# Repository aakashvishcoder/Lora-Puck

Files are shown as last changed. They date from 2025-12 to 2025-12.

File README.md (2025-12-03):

# Lora Puck

This is my version of a Lora Puck, which is a compact, low-power wireless communication module that can send and receive data from several kilometers away! This puck has several unique features and parts (as listed below), and includes a temperature sensor as well! This is one of my first ever PCBs, so it most definitely has some flaws!

# Features:
- USBC Receptacle
- Programmable Microcontroller

# Images:






# Build of Materials (BOM)

| Item | Description | Qty | Product link | Price w/ Tax ($) | Running Total |
|---|---|-----|---|---|---|
| Capacitor | 100nF (0.1uF) | 13 | [link](https://jlcpcb.com/partdetail/1877-CL05B104KO5NNNC/C1525) | $0.21 | $0.21 |
| Capacitor | 1uF | 2 | [link](https://jlcpcb.com/partdetail/53938-CL05A105KA5NQNC/C52923) | $0.06 | $0.27 |
| Capacitor | 47nF | 1 | [link](https://jlcpcb.com/partdetail/YAGEO-CC0402KRX7R9BB473/C1532) | $0.02 | $0.29 |
| Capacitor | 47pF | 1 | [link](https://jlcpcb.com/partdetail/YAGEO-CC0402JRNPO9BN470/C1549) | $0.01 | $0.30 |
| Capacitor | 1nF | 1 | [link](https://jlcpcb.com/partdetail/YAGEO-CC0402KRX7R9BB102/C1522) | $0.01 | $0.31 |
| Capacitor | 39pF | 1 | [link](https://jlcpcb.com/partdetail/YAGEO-CC0402JRNPO9BN390/C1548) | $0.01 | $0.32 |
| Capacitor | 3.3pF | 4 | [link](https://jlcpcb.com/partdetail/YAGEO-CC0402JRNPO9BN3R3/C1546) | $0.04 | $0.36 |
| Capacitor | 10uF | 2 | [link](https://jlcpcb.com/partdetail/SamsungElectro-CL05A106MQ5NUNC/C15525) | $0.06 | $0.42 |
| Capacitor | 470nF | 1 | [link](https://jlcpcb.com/partdetail/YAGEO-CC0402KRX7R9BB471/C1779) | $0.02 | $0.44 |
| Inductor | 15uH | 1 | [link](https://jlcpcb.com/partdetail/Sunlord-SDCL1005C150KTDF/C285676) | $0.05 | $0.49 |
| Inductor | 47nH | 1 | [link](https://jlcpcb.com/partdetail/JohansonTech-L-0402_47nH/C284438) | $0.05 | $0.54 |
| Inductor | 9.1nH | 1 | [link](https://jlcpcb.com/partdetail/JohansonTech-L-0402_9_1nH/C284437) | $0.05 | $0.59 |
| Ferrite Bead | Ferrite 0402 | 1 | [link](https://jlcpcb.com/partdetail/Sunlord-SDCL1005C4N7STDF/C8589) | $0.01 | $0.60 |
| Balun | Johanson 0900FM15K0039 | 1 | [link](https://jlcpcb.com/partdetail/JohansonTech-0900FM15K0039/C284439) | $0.85 | $1.45 |
| Resistor | 10k | 1 | [link](https://jlcpcb.com/partdetail/UNIROYAL-0402WGF1002TCE/C25804) | $0.01 | $1.46 |
| Resistor | 4.7k | 2 | [link](https://jlcpcb.com/partdetail/UNIROYAL-0402WGF4701TCE/C25867) | $0.02 | $1.48 |
| Resistor | 27.4Ω | 2 | [link](https://jlcpcb.com/partdetail/UNIROYAL-0402WGF270JTCE/C23154) | $0.02 | $1.50 |
| Resistor | 1k | 2 | [link](https://jlcpcb.com/partdetail/UNIROYAL-0402WGF1001TCE/C11702) | $0.02 | $1.52 |
| Resistor | 100Ω | 1 | [link](https://jlcpcb.com/partdetail/UNIROYAL-0402WGF1000TCE/C25086) | $0.01 | $1.53 |
| Resistor | 5.1k | 2 | [link](https://jlcpcb.com/partdetail/UNIROYAL-0402WGF5101TCE/C25905) | $0.02 | $1.55 |
| Switch | Tactile Button | 2 | [link](https://jlcpcb.com/partdetail/XKBConnectivity-TS1187ABAB/C318884) | $0.84 | $2.39 |
| USB Receptacle | USB-C 16P | 1 | [link](https://jlcpcb.com/partdetail/Korean_HropartsElec-TYPEC31M12/C165948) | $0.85 | $3.24 |
| IC | LoRa SX1262 | 1 | [link](https://jlcpcb.com/partdetail/Semtech-SX1262IMLTRT/C967207) | $6.50 | $9.74 |
| IC | RP2040 MCU | 1 | [link](https://jlcpcb.com/partdetail/RaspberryPi-RP2040/C2040) | $4.58 | $14.32 |
| IC | Flash W25Q128JVS | 1 | [link](https://jlcpcb.com/partdetail/Winbond-W25Q128JVSIQ/C97521) | $2.67 | $16.99 |
| IC | RF Switch PE4259 | 1 | [link](https://jlcpcb.com/partdetail/PeregrineSemiconductor-PE4259/C285440) | $1.20 | $18.19 |
| IC | Regulator AP2112K-3.3 | 1 | [link](https://jlcpcb.com/partdetail/DiodesInc-AP2112K3_3TRG1/C15630) | $0.12 | $18.31 |
| Sensor | SHTC3 Humidity/Temp | 1 | [link](https://jlcpcb.com/partdetail/Sensirion-SHTC3/C2844388) | $2.80 | $21.11 |
| Crystal | 32MHz 3225 | 1 | [link](https://jlcpcb.com/partdetail/YXC-X322532MSB4SI/C9003) | $0.32 | $21.43 |
| Crystal | 12MHz 3225 | 1 | [link](https://jlcpcb.com/partdetail/YXC-X322512MSB4SI/C9002) | $0.32 | $21.75 |
| LoRa-Puck PCB | PCBA board assembly | 1 | [link](https://cart.jlcpcb.com/) | $43.94 | $65.69 |

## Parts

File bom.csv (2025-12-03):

Item | Description | Quantity | Product link | Price w/ Tax ($) | Running Total
Capacitor | 100nF (0.1uF) | 13 | https://jlcpcb.com/partdetail/1877-CL05B104KO5NNNC/C1525 | $0.21 | $0.21
Capacitor | 1uF | 2 | https://jlcpcb.com/partdetail/53938-CL05A105KA5NQNC/C52923 | $0.06 | $0.27
Capacitor | 47nF | 1 | https://jlcpcb.com/partdetail/YAGEO-CC0402KRX7R9BB473/C1532 | $0.02 | $0.29
Capacitor | 47pF | 1 | https://jlcpcb.com/partdetail/YAGEO-CC0402JRNPO9BN470/C1549 | $0.01 | $0.30
Capacitor | 1nF | 1 | https://jlcpcb.com/partdetail/YAGEO-CC0402KRX7R9BB102/C1522 | $0.01 | $0.31
Capacitor | 39pF | 1 | https://jlcpcb.com/partdetail/YAGEO-CC0402JRNPO9BN390/C1548 | $0.01 | $0.32
Capacitor | 3.3pF | 4 | https://jlcpcb.com/partdetail/YAGEO-CC0402JRNPO9BN3R3/C1546 | $0.04 | $0.36
Capacitor | 10uF | 2 | https://jlcpcb.com/partdetail/SamsungElectro-CL05A106MQ5NUNC/C15525 | $0.06 | $0.42
Capacitor | 470nF | 1 | https://jlcpcb.com/partdetail/YAGEO-CC0402KRX7R9BB471/C1779 | $0.02 | $0.44
Inductor | 15uH | 1 | https://jlcpcb.com/partdetail/Sunlord-SDCL1005C150KTDF/C285676 | $0.05 | $0.49
Inductor | 47nH | 1 | https://jlcpcb.com/partdetail/JohansonTech-L-0402_47nH/C284438 | $0.05 | $0.54
Inductor | 9.1nH | 1 | https://jlcpcb.com/partdetail/JohansonTech-L-0402_9_1nH/C284437 | $0.05 | $0.59
Ferrite Bead | Ferrite 0402 | 1 | https://jlcpcb.com/partdetail/Sunlord-SDCL1005C4N7STDF/C8589 | $0.01 | $0.60
Balun | Johanson 0900FM15K0039 | 1 | https://jlcpcb.com/partdetail/JohansonTech-0900FM15K0039/C284439 | $0.85 | $1.45
Resistor | 10k | 1 | https://jlcpcb.com/partdetail/UNIROYAL-0402WGF1002TCE/C25804 | $0.01 | $1.46
Resistor | 4.7k | 2 | https://jlcpcb.com/partdetail/UNIROYAL-0402WGF4701TCE/C25867 | $0.02 | $1.48
Resistor | 27.4Ω | 2 | https://jlcpcb.com/partdetail/UNIROYAL-0402WGF270JTCE/C23154 | $0.02 | $1.50
Resistor | 1k | 2 | https://jlcpcb.com/partdetail/UNIROYAL-0402WGF1001TCE/C11702 | $0.02 | $1.52
Resistor | 100Ω | 1 | https://jlcpcb.com/partdetail/UNIROYAL-0402WGF1000TCE/C25086 | $0.01 | $1.53
Resistor | 5.1k | 2 | https://jlcpcb.com/partdetail/UNIROYAL-0402WGF5101TCE/C25905 | $0.02 | $1.55
Switch | Tactile Button | 2 | https://jlcpcb.com/partdetail/XKBConnectivity-TS1187ABAB/C318884 | $0.84 | $2.39
USB Receptacle | USB-C 16P | 1 | https://jlcpcb.com/partdetail/Korean_HropartsElec-TYPEC31M12/C165948 | $0.85 | $3.24
IC | LoRa SX1262 | 1 | https://jlcpcb.com/partdetail/Semtech-SX1262IMLTRT/C967207 | $6.50 | $9.74
IC | RP2040 MCU | 1 | https://jlcpcb.com/partdetail/RaspberryPi-RP2040/C2040 | $4.58 | $14.32
IC | Flash W25Q128JVS | 1 | https://jlcpcb.com/partdetail/Winbond-W25Q128JVSIQ/C97521 | $2.67 | $16.99
IC | RF Switch PE4259 | 1 | https://jlcpcb.com/partdetail/PeregrineSemiconductor-PE4259/C285440 | $1.20 | $18.19
IC | Regulator AP2112K-3.3 | 1 | https://jlcpcb.com/partdetail/DiodesInc-AP2112K3_3TRG1/C15630 | $0.12 | $18.31
Sensor | SHTC3 Humidity/Temp | 1 | https://jlcpcb.com/partdetail/Sensirion-SHTC3/C2844388 | $2.80 | $21.11
Crystal | 32MHz 3225 | 1 | https://jlcpcb.com/partdetail/YXC-X322532MSB4SI/C9003 | $0.32 | $21.43
Crystal | 12MHz 3225 | 1 | https://jlcpcb.com/partdetail/YXC-X322512MSB4SI/C9002 | $0.32 | $21.75
LoRa-Puck PCB | PCBA board assembly | 1 | N/A (https://cart.jlcpcb.com/) | $43.94 | $65.69

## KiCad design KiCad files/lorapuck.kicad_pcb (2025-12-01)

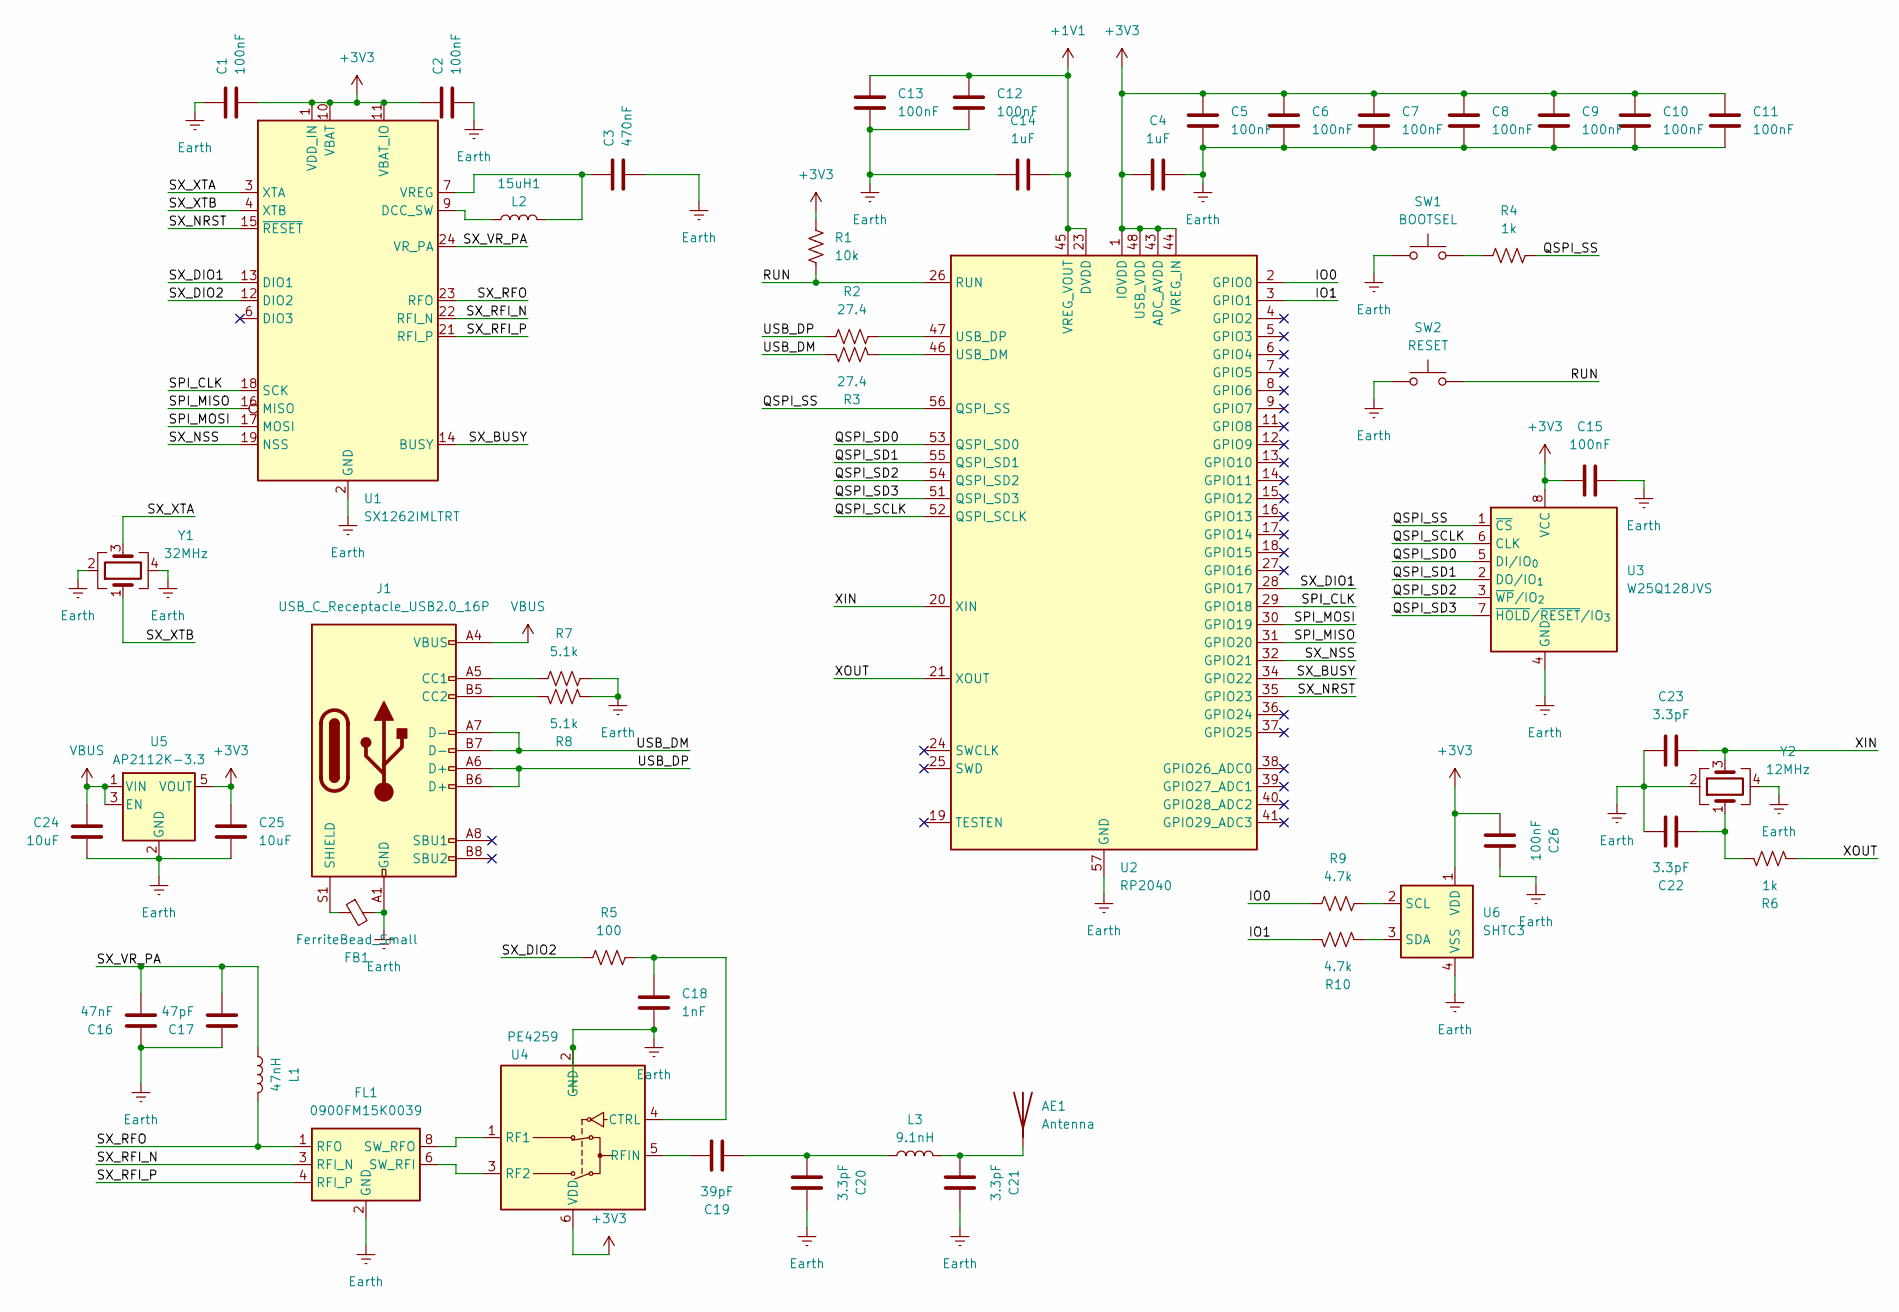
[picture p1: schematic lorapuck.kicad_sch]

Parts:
15uH1: L2; L_0402_1005Metric
AE1: Antenna; PinSocket_1x01_P2.54mm_Vertical
C1, C2, C5, C6, C7, C8, C9, C10, C11, C12, C13, C15, C26: 100nF; C_0402_1005Metric
C3: 470nF; C_0402_1005Metric
C4, C14: 1uF; C_0402_1005Metric
C16: 47nF; C_0402_1005Metric
C17: 47pF; C_0402_1005Metric
C18: 1nF; C_0402_1005Metric
C19: 39pF; C_0402_1005Metric
C20, C21, C22, C23: 3.3pF; C_0402_1005Metric
C24, C25: 10uF; C_0402_1005Metric
FB1: FerriteBead_Small; L_0402_1005Metric
FL1: 0900FM15K0039; Balun_Johanson_0900FM15K0039
J1: USB_C_Receptacle_USB2.0_16P; USB_C_Receptacle_GCT_USB4105-xx-A_16P_TopMnt_Horizontal
L1: 47nH; L_0402_1005Metric
L3: 9.1nH; L_0402_1005Metric
R1: 10k; R_0402_1005Metric
R2, R3: 27.4; R_0402_1005Metric
R4, R6: 1k; R_0402_1005Metric
R5: 100; R_0402_1005Metric
R7, R8: 5.1k; R_0402_1005Metric
R9, R10: 4.7k; R_0402_1005Metric
SW1: BOOTSEL; SW_Tactile_SPST_NO_Straight_CK_PTS636Sx25SMTRLFS
SW2: RESET; SW_Tactile_SPST_NO_Straight_CK_PTS636Sx25SMTRLFS
U1: SX1262IMLTRT; QFN-24-1EP_4x4mm_P0.5mm_EP2.6x2.6mm
U2: RP2040; QFN-56-1EP_7x7mm_P0.4mm_EP3.2x3.2mm
U3: W25Q128JVS; SOIC-8_5.3x5.3mm_P1.27mm
U4: PE4259; SOT-363_SC-70-6
U5: AP2112K-3.3; SOT-23-5
U6: SHTC3; Sensirion_DFN-4-1EP_2x2mm_P1mm_EP0.7x1.6mm
Y1: 32MHz; Crystal_SMD_3225-4Pin_3.2x2.5mm
Y2: 12MHz; Crystal_SMD_Abracon_ABM8G-4Pin_3.2x2.5mm

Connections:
+1V1: C12.2, C13.2, C14.2, U2.23 (DVDD), U2.45 (VREG_VOUT), U2.50 (DVDD)
+3V3: C1.2, C2.1, C4.1, C5.2, C6.2, C7.2, C8.2, C9.2, C10.2, C11.2, C15.2, C25.1, C26.2, R1.1, U1.1 (VDD_IN), U1.10 (VBAT), U1.11 (VBAT_IO), U2.1 (IOVDD), U2.10 (IOVDD), U2.22 (IOVDD), U2.33 (IOVDD), U2.42 (IOVDD), U2.43 (ADC_AVDD), U2.44 (VREG_IN), U2.48 (USB_VDD), U2.49 (IOVDD), U3.8 (VCC), U4.6 (VDD), U5.5 (VOUT), U6.1 (VDD)
/<NO NET>: U1.15 (~RESET), U2.35 (GPIO23)
/IO0: R9.1, U2.2 (GPIO0)
/IO1: R10.2, U2.3 (GPIO1)
/QSPI_SCLK: U2.52 (QSPI_SCLK), U3.6 (CLK)
/QSPI_SD0: U2.53 (QSPI_SD0), U3.5 (DI/IO_{0})
/QSPI_SD1: U2.55 (QSPI_SD1), U3.2 (DO/IO_{1})
/QSPI_SD2: U2.54 (QSPI_SD2), U3.3 (~WP/IO_{2})
/QSPI_SD3: U2.51 (QSPI_SD3), U3.7 (~HOLD/~RESET/IO_{3})
/QSPI_SS: R4.1, U2.56 (QSPI_SS), U3.1 (~CS)
/RUN: R1.2, SW2.2, U2.26 (RUN)
/SPI_CLK: U1.18 (SCK), U2.29 (GPIO18)
/SPI_MISO: U1.16 (MISO), U2.31 (GPIO20)
/SPI_MOSI: U1.17 (MOSI), U2.30 (GPIO19)
/SX_BUSY: U1.14 (BUSY), U2.34 (GPIO22)
/SX_DIO1: U1.13 (DIO1), U2.28 (GPIO17)
/SX_DIO2: R5.1, U1.12 (DIO2)
/SX_NSS: U1.19 (NSS), U2.32 (GPIO21)
/SX_RFI_N: FL1.3 (RFI_N), U1.22 (RFI_N)
/SX_RFI_P: FL1.4 (RFI_P), U1.21 (RFI_P)
/SX_RFO: FL1.1 (RFO), L1.2, U1.23 (RFO)
/SX_VR_PA: C16.2, C17.2, L1.1, U1.24 (VR_PA)
/SX_XTA: U1.3 (XTA), Y1.3
/SX_XTB: U1.4 (XTB), Y1.1
/USB_DM: J1.A7 (D-), J1.B7 (D-), R3.2
/USB_DP: J1.A6 (D+), J1.B6 (D+), R2.2
/XIN: C23.1, U2.20 (XIN), Y2.3
/XOUT: R6.2, U2.21 (XOUT)
Earth: C1.1, C2.2, C3.2, C4.2, C5.1, C6.1, C7.1, C8.1, C9.1, C10.1, C11.1, C12.1, C13.1, C14.1, C15.1, C16.1, C17.1, C18.2, C20.1, C21.1, C22.1, C23.2, C24.2, C25.2, C26.1, FB1.2, FL1.2 (GND), FL1.5 (GND), FL1.7 (GND), FL1.9 (GND), FL1.10 (GND), J1.A1 (GND), J1.A12 (GND), J1.B1 (GND), J1.B12 (GND), R7.2, R8.2, SW1.1, SW2.1, U1.2 (GND), U1.5 (GND), U1.8 (GND), U1.20 (GND), U1.25 (GND), U2.57 (GND), U3.4 (GND), U4.2 (GND), U5.2 (GND), U6.4 (VSS), Y1.2, Y1.4, Y2.2, Y2.4
unnamed: AE1.1 (A), C21.2, L3.2
unnamed: C19.2, C20.2, L3.1
unnamed: C22.2, R6.1, Y2.1
unnamed: FL1.6 (SW_RFI), U4.3 (RF2)
unnamed: FL1.8 (SW_RFO), U4.1 (RF1)
unnamed: J1.A5 (CC1), R7.1
unnamed: J1.B5 (CC2), R8.1
unnamed: FB1.1, J1.S1 (SHIELD)
unnamed: R4.2, SW1.2
unnamed: 15uH1.1, U1.9 (DCC_SW)
unnamed: 15uH1.2, C3.1, U1.7 (VREG)
unnamed: R3.1, U2.46 (USB_DM)
unnamed: R2.1, U2.47 (USB_DP)
unnamed: C18.1, R5.2, U4.4 (CTRL)
unnamed: C19.1, U4.5 (RFIN)
unnamed: R9.2, U6.2 (SCL)
unnamed: R10.1, U6.3 (SDA)
VBUS: C24.1, J1.A4 (VBUS), J1.A9 (VBUS), J1.B4 (VBUS), J1.B9 (VBUS), U5.1 (VIN), U5.3 (EN)

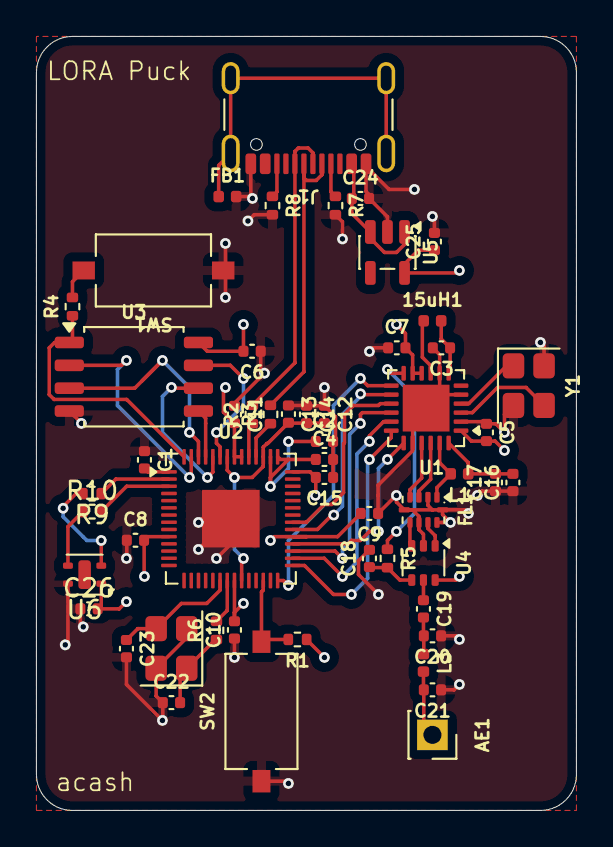
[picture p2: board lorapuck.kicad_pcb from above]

Board: 4 copper layers, 30.0 x 43.0 mm, 53 parts (0 on the bottom side), 48 nets.

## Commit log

2025-11-28 all the kicad files added
    [lorapuck.kicad_pcb, lorapuck.kicad_sch]
2025-12-01 edited the usbc receptacle and added a weather sensor!
    [lorapuck.kicad_pcb, lorapuck.kicad_sch]
2025-12-01 quick change to the pcb
2025-12-01 Update BOM with SHTC3 datasheet link
    Added datasheet link for SHTC3 sensor in the BOM.
2025-12-03 added gerber + fixed gitignore + finished bom
    [bom.csv, designators.csv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]
2025-12-03 Revise BOM section in README.md
    Updated the Bill of Materials (BOM) section with new item details, including descriptions, quantities, product links, and prices.
2025-12-03 changed the file name
    [bom.csv]
2025-12-03 cleaned up the files
    [lorapuck.kicad_pcb, lorapuck.kicad_sch]
2025-12-04 fixed some issues with pcb
    [lorapuck.kicad_pcb]
